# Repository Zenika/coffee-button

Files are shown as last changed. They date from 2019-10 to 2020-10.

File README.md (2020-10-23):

<h1 align="center">Welcome to Coffee Button 👋</h1>
<p>
  <a href="https://www.gnu.org/licenses/gpl-3.0.html" target="_blank">
    
  </a>
</p>

> Order your coffee in one click or everything else  
> Click the button, the raspberry boot, call your webhook then shutdown

## Prototype

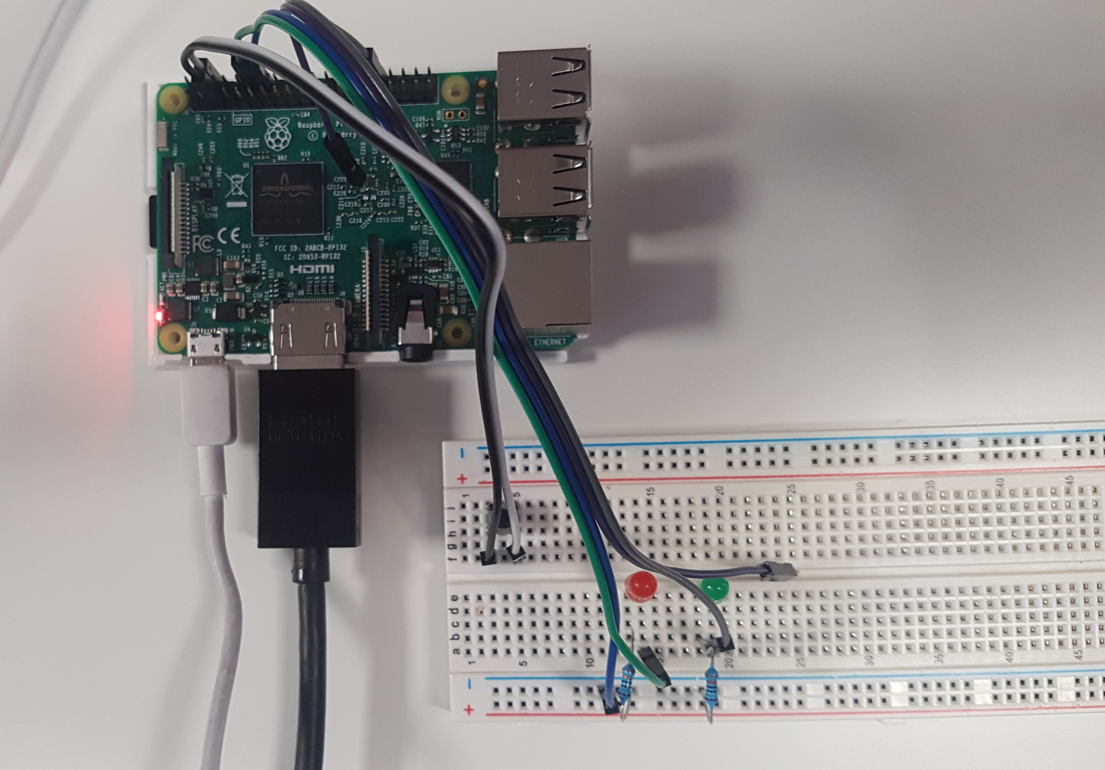
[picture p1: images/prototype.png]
Prototype


## Install

### What you need to run the project

 - a Raspberry Pi with Wifi, or ethernet connection if you like cables
 - an SD card (2GB should do)
 - 2 leds (red & green, or anything you see fit) with 330Ω resitors and cables
 - a push button with cables
 - optionnaly a breadboard, to check the connections before soldering the elements

LED Red LED example
Resistor 330Ω Resistor

### How to build

 * Connect the push button on pins 5 & 6 _(SCL & Ground)_, so the click will wake it.
 * Connect the green led and a resistor on pins 32 & 34 _(PWM0 & Ground)_.
 * Connect the red led and the other resistor on pins 12 & 14 _(PWM0 & Ground)_.

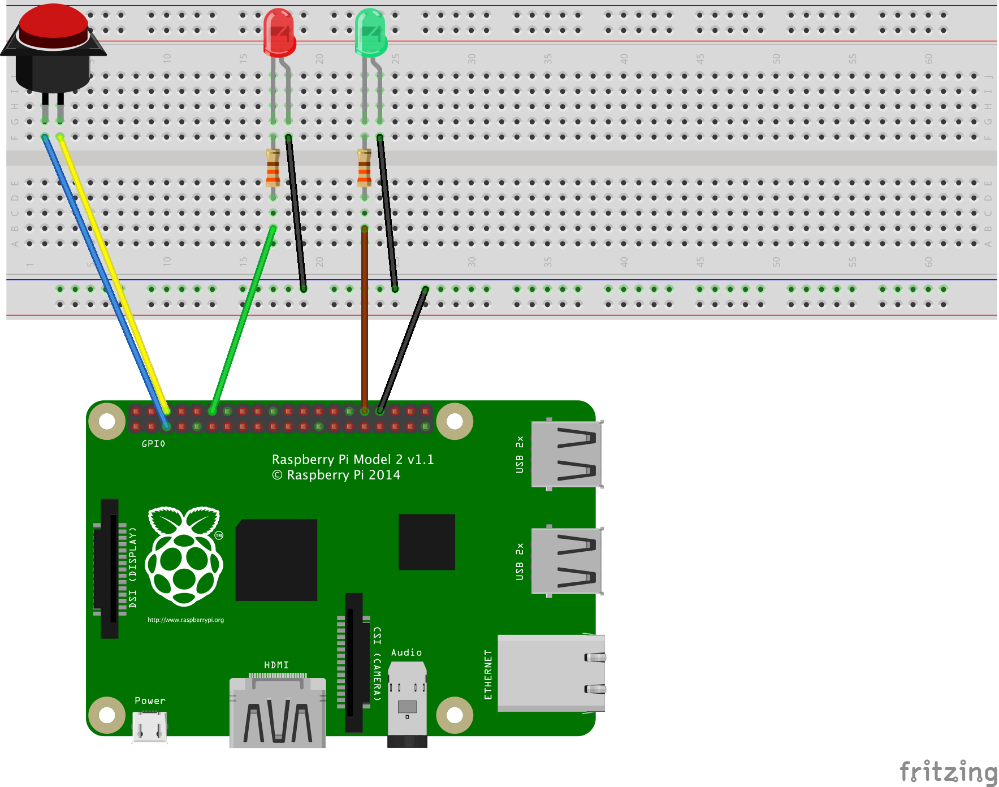
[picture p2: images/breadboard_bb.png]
Breadboard


### How to setup

 * Get a Raspbian lite image from the [official page](https://www.raspberrypi.org/downloads/raspbian/)
 * Burn it on the SD card: ex. on Linux/BSD -> `sudo dd bs=1M conv=noerror,sync status=progress if=<path_to_your_img/name.img> of=<path_to_mounted_SDcard>`
 * Start the pi with screen and keyboard to configure Wifi, using the `sudo raspi-config` command
 * Get sources. Either with git or by hand : 
  * Git : 
  ```
  apt install -y git
  git clone https://github.com/Zenika/coffee-button
  ```
  * copy source code to `/home/pi/coffee-button` on the pi
 * Make a copy of `.env.example` to `.env` and add the webhook and token you created. We used Zapier to handle the request and filter the Authorization header then send the email and Slack notification. You also need to set the number of days between orders (__integer required__)
 * Setting the `DRY_RUN` variable to `true` will setup an empty run of the script for the next time it will be plugged
 * Test the script on pi by running `/home/pi/coffee-button/init.sh`
 * Add `init.sh` to the boot process : edit `/etc/rc.local` and add a line `/home/pi/coffee-button/init.sh`
 
 **Warning** :warning: _Doing this last action will prevent you to access the pi via keyboard or SSH as it will shut it down immediatly after request is sent and will then force you to mount the SD card on your computer again!. Be sure that everything is in order before that or comment the last line of the `init.sh` script_

## Usage

Push the button !
Leds will flashes after a few seconds (if nothing happens don't panic and wait longer) then green if the request was sent or already sent in the previous 48h, red if something went wrong.

## Author

👤 **Jérémy Lejeune**

* Github: [@yodur2potassium](https://github.com/yodur2potassium)

👤 **Lucas Dupuy**

* Github: [@louckousse](https://github.com/louckousse)

## Show your support

Give a ⭐️ if this project helped you!

## 📝 License

Copyright © 2019 [Jérémy Lejeune](https://github.com/yodur2potassium), [Lucas Dupuy](https://github.com/louckousse).<br />
This project is [GPL 3](https://www.gnu.org/licenses/gpl-3.0.html) licensed.

***
_This README was generated with ❤️ by [readme-md-generator](https://github.com/kefranabg/readme-md-generator)_

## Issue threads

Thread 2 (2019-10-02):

Blinking leds

yodur2potassium, 2019-10-02:
We may want to have a blinking green led as the app start and send the request, then going fixed green for a few seconds if ok and red if not.

Closed 2019-10-02.

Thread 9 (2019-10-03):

Print the case

yodur2potassium, 2019-10-03:
We found a case and button, so we need to print the elements and assemble.

yodur2potassium, 2019-10-04:
On its way...
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

yodur2potassium, 2019-10-07:
Done. Need soldering and final glueing...

Closed 2019-10-09.

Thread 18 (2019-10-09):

New case for the V2

yodur2potassium, 2019-10-09:
As we think of a new hardware to run the project, we need to find a new case and button for it. And a cool improvement could be to use a switch with a little more length of travel?

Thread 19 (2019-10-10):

A pending order notification would be nice

yodur2potassium, 2019-10-10:
As discussed with @aorenge, displaying a notification that an order as been placed already, on the Zenboard ideally, would be a great improvement on the coffe button. And thus preventing multiple orders to be placed every 2 days.
Question: how to flag that the order has been received?

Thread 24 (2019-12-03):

Add logs to the payload sent to webhook

yodur2potassium, 2019-12-03:
In order to help debug the button and gather informations on the last uses, we need to add the last lines of logs in the payload sent to the webhook.
For now, the webhook keep the logs for a month.

yodur2potassium, 2019-12-03:
Actually, there was already, but the `curl` request doesn't seem to work recently...

Closed 2019-12-10.

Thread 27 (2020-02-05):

No update on date at startup

yodur2potassium, 2020-02-05:
Found this fun bug with the logs: the Rapsberry not having any battery to run an internal clock, it doesn't keep track of date between uses (it goes to deep sleep after sending the request). So the next time you click on it, it just had elapsed 20 seconds since last time... 🤣 Thus not sending the coffee order 😱
We need to fix that by synchronizing the clock on startup.
https://raspberrypi.stackexchange.com/questions/8231/how-to-force-ntpd-to-update-date-time-after-boot

Closed 2020-02-13.

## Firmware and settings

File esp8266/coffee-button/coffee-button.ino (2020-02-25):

#include <OneButton.h>
#include <ESP8266WiFi.h>
#include <WiFiClientSecure.h>

#define GREEN_LED 2
#define RED_LED 13

// edit the SSID & password to match your local network
const char* ssid = "<insert_ssid_here>";
const char* password = "<insert_pwd_here>";
const char* host = "hooks.zapier.com"; // edit the host adress, ip address etc. 
String url = "<insert_hook_url>"; // edit the hook url 
const int httpsPort = 443;
// SHA1 fingerprint of the certificate
// if you use another provider, be sure to change the fingerprint
const char fingerprint[] PROGMEM = "AF 21 4A 6C 2C E4 CE 6E 99 7B B8 EA 58 CF 57 6B C2 35 A4 0D";
const String request = "POST " + url + " HTTP/1.1\r\n" +
               "Host: " + host + "\r\n" +
               "Content-Type: application/x-www-form-urlencoded" + "\r\n" +
               "Content-Length: 21" + "\r\n\r\n" +
               "body=BringOnTheCoffee" + "\r\n" +
               "Connection: close\r\n\r\n";

OneButton button(D6, true);
WiFiClientSecure httpsClient;

void connectAndSendRequest() {
  // Connecting to host and send request
  Serial.print("HTTPS Connecting");
  int r=0; //retry counter
  while((!httpsClient.connect(host, httpsPort)) && (r < 30)){
      delay(100);
      Serial.print(".");
      r++;
  }
  if (r==30) {
    koLed();
    Serial.println("Connection failed");
  }
  else {
    Serial.println("Connected to host");
  }
  String address = host + url;
  //POST Data
  Serial.print("Requesting URL: ");
  Serial.println(address);
  blinkLeds();

  httpsClient.print(request);

  Serial.println("request sent");

  while (httpsClient.connected()) {
    String line = httpsClient.readStringUntil('\n');
    if (line == "\r") {
      Serial.println("headers received");
      break;
    }
  }

  Serial.println("reply was:");
  Serial.println("==========");
  String line;
  while(httpsClient.available()){
    line = httpsClient.readStringUntil('\n');  //Read Line by Line
    Serial.println(line); //Print response
    if (line.startsWith("{\"status\": \"success\"")) {
      Serial.println("Command was sent!");
      okLed();
    } else {
      Serial.println("Something went wrong!");
      koLed();
    }
  }
  Serial.println("==========");
  Serial.println("closing connection");
}

void setup() {
  // Initializing LEDs
  pinMode(GREEN_LED, OUTPUT);
  pinMode(RED_LED, OUTPUT);
  digitalWrite(GREEN_LED, LOW);
  digitalWrite(RED_LED, LOW);

  button.attachClick(connectAndSendRequest);

  // Initializing Wifi-connection
  Serial.begin(115200);
  // We start by connecting to a WiFi network
  Serial.print("Connecting to ");
  Serial.println(ssid);
  /* Explicitly set the ESP8266 to be a WiFi-client, otherwise, it by default,
    would try to act as both a client and an access-point and could cause
    network-issues with your other WiFi-devices on your WiFi-network. */
  WiFi.mode(WIFI_STA);
  WiFi.begin(ssid, password);
  while (WiFi.status() != WL_CONNECTED) {
    delay(500);
    Serial.print(".");
  }
  Serial.println("");
  Serial.println("WiFi connected");
  Serial.println("IP address: ");
  Serial.println(WiFi.localIP());
  // Setting up connexion to host
 
  Serial.println(host);
 
  Serial.printf("Using fingerprint '%s'\n", fingerprint);
  httpsClient.setFingerprint(fingerprint);
  httpsClient.setTimeout(15000); // 15 Seconds
  flashLed(GREEN_LED);
}

void okLed() {
  digitalWrite(GREEN_LED, HIGH);
  delay(3000);
  digitalWrite(GREEN_LED, LOW);
}

void koLed() {
  digitalWrite(RED_LED, HIGH);
  delay(3000);
  digitalWrite(RED_LED, LOW);
}

void flashLed(int led) {
  for (int i=0;i<4;i++) {
    digitalWrite(led, HIGH);
    delay(250);
    digitalWrite(led, LOW);
    delay(250);
  }
}

void blinkLeds() {
  for (int i=0;i<11;i++) {
    digitalWrite(GREEN_LED, HIGH);
    digitalWrite(RED_LED, LOW);
    delay(125);
    digitalWrite(GREEN_LED, LOW);
    digitalWrite(RED_LED, HIGH);
    delay(125);
  }
  digitalWrite(GREEN_LED, LOW);
  digitalWrite(RED_LED, LOW);
}

void loop() {
  button.tick();
  delay(10);
}

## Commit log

2019-10-02 add python for led test
2019-10-02 Test on leds switch
2019-10-02 Add boot, ok and ko led signal
2019-10-08 :pencil: improve install process (#15)
    * Add images && WIP on README
    * Oups, removed file
    * Remove image
    * Add setup and change usage
    * Typo
    * Remove list
    * Typo, again
    * Add warning message
    * Few improvments and typo
    * :memo: Add breadboard (#16)
    * Update README.md
    * Update README.md
    * Update README.md
    * Review changes
    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
    [breadboard.fzz]

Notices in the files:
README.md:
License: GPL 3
